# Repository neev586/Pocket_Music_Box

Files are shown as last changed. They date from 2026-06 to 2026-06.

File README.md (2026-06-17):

# Pocket Music Box

A small 3D-printed music box that plays MP3s when the lid opens and pauses when it closes — like a classic ballerina music box, but with your own songs.

## How It Works

- **Open the lid** → music plays
- **Close the lid** → music pauses instantly
- **Reopen within 20 seconds** → resumes where it left off
- **Reopen after 20 seconds** → restarts the track from the beginning
- **Short press the button** → skip to the next track
- **Long press the button (0.5s+)** → cycle through 5 volume levels (mute → low → medium → high → max)
- **Lid stays closed for 60 seconds** → ESP32 enters deep sleep to save battery
- **Deep sleep** → wakes every 1.5 seconds to check if the lid is open

## Components

| Component | Specification |
|---|---|
| Microcontroller | ESP32-C3 Super Mini |
| Audio module | MP3-TF-16P (DFPlayer Mini clone) |
| Speaker | 40mm 8Ω |
| Battery | 3.7V LiPo, 300mAh (32×20×6mm) |
| Charger | TP4056 USB-C module |
| Light sensor | Photoresistor (LDR) |
| Button | 6×6mm tactile push button |
| Resistor | 10kΩ × 1 (LDR pull-down) |
| SD card | MicroSD, FAT32, 32GB or smaller |

## Wiring

```
POWER
  Battery +        → TP4056 B+
  Battery −        → TP4056 B−
  TP4056 OUT+      → ESP32 5V pin + DFPlayer VCC
  TP4056 OUT−      → GND rail (shared by all components)

ESP32 → DFPlayer (serial)
  GPIO 7 (TX)      → DFPlayer RX
  GPIO 6 (RX)      → DFPlayer TX

DFPlayer → Speaker
  SPK_1            → Speaker +
  SPK_2            → Speaker −

Button
  GPIO 9           → one leg
  other leg        → GND
  (uses internal pull-up, no external resistor needed)

LDR (light sensor)
  3.3V → LDR → junction → 10kΩ → GND
                 ↓
              GPIO 0
```

## SD Card Setup

- Format as **FAT32** (not exFAT or NTFS)
- Maximum **32GB** card
- Place MP3 files in the **root folder** (not in subfolders)
- Name files: `001.mp3`, `002.mp3`, `003.mp3`, etc.

## Software Setup

### Arduino IDE Settings

- **Board:** Nologo ESP32C3 Super Mini (or ESP32C3 Dev Module)
- **USB CDC On Boot:** Enabled
- **Flash Frequency:** 80MHz

### Required Library

- [DFRobotDFPlayerMini](https://github.com/DFRobot/DFRobotDFPlayerMini) — install via Arduino Library Manager

### First Upload

If the board connects and disconnects repeatedly when first plugged in, hold the **BOOT button** while plugging in the USB cable, then release after 1 second. Upload your sketch in this state. Subsequent uploads will work normally.

## Enclosure

The enclosure is a 3D-printed hinged box designed to house all components.

### Dimensions

- **Exterior (closed):** 68 × 60 × 52mm (68.5mm deep including hinge)
- **Interior:** 62.4 × 54.4 × 43.2mm
- **Wall thickness:** 2.8mm
- **Lid thickness:** 6mm

### Features

- 5-knuckle barrel hinge (2mm pin)
- Speaker grille on the front wall (40mm, concentric ring pattern)
- 6.4mm square button hole on the right wall
- SD card module holder on the right wall (flat mount, card accessible from top with lid open)
- Battery cradle (back-left)
- USB-C charge port opening on the back wall (14 × 8mm)

### Printing

- **Material:** PLA
- **Layer height:** 0.2mm
- **Walls:** 3 perimeters
- **Infill:** 15%
- **Supports:** none for the body; light support may be needed under the lid's hinge knuckles
- **Hinge pin:** insert a 2mm steel rod or length of filament after printing

### Files

- `enclosure_body.stl` — print floor-down as-is
- `enclosure_lid.stl` — pre-oriented top-face-down for printing
- `enclosure.py` — parametric source (Python + trimesh), edit variables and re-run to customize

## Deep Sleep & Power

The ESP32-C3 draws ~50–80mA when active. After 60 seconds with the lid closed, it enters deep sleep (~0.1–0.2mA average with 1.5-second wake checks). The 300mAh battery lasts:

- **Active playback:** ~4–5 hours
- **Deep sleep:** ~60–90 days

## Troubleshooting

| Symptom | Likely Cause | Fix |
|---|---|---|
| ESP32 connects/disconnects on USB | Empty flash | Hold BOOT button while plugging in, then upload |
| DFPlayer not found | Loose wiring or power issue | Check and reflow solder joints on VCC, GND, TX, RX |
| No sound but DFPlayer online | SD card issue | Reformat as FAT32, rename files to 001.mp3 format |
| Audio plays but is silent | Speaker wiring | Check SPK_1 and SPK_2 connections |
| LDR always reads 4095 | Missing pull-down resistor | Add 10kΩ between GPIO 0 and GND |
| Box won't wake from sleep | LDR covered or broken | Check that light reaches the LDR when lid opens |
| Stops working after charging | Solder joint cracked from heat | Reflow all DFPlayer solder joints |
| Audio distorts at max volume | Speaker overdriven | Lower top volume step from 30 to 25 |
| Stuck on "Initialization failed" | DFPlayer boots slower than ESP32 | Press reset button; if persistent, check wiring |

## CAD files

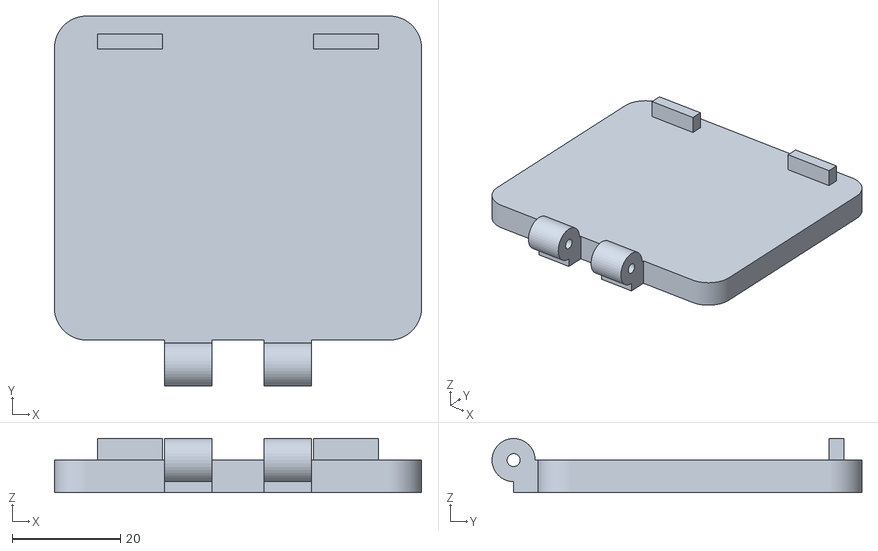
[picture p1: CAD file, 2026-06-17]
Enclosure/enclosure_lid_final.stl
68.0 x 68.5 x 10.0

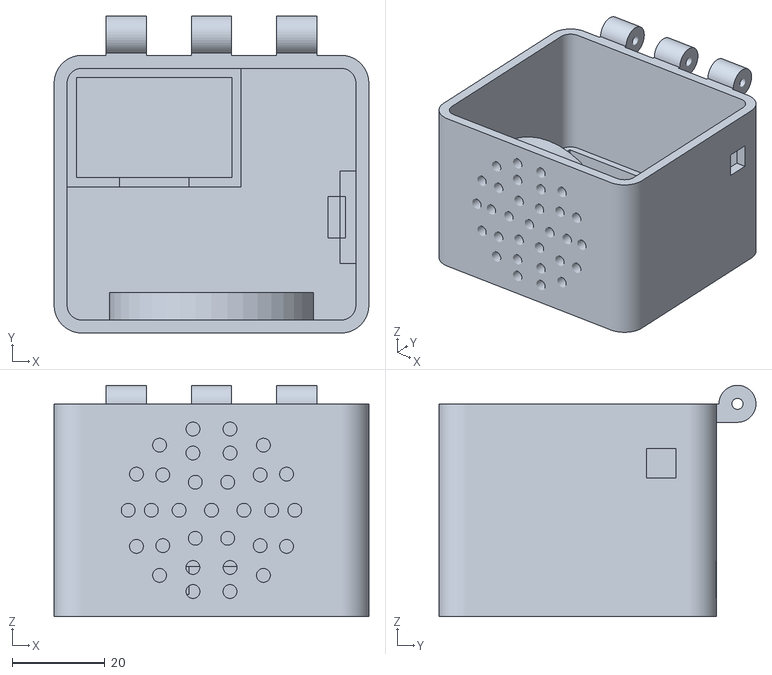
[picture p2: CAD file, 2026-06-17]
Enclosure/enclosure_body_final.stl
68.0 x 68.5 x 50.0

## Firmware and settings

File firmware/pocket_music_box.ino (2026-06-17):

#include "Arduino.h"
#include "DFRobotDFPlayerMini.h"
#include <Preferences.h>

// ==========================================
// PIN DEFINITIONS
// ==========================================
#define FPS_RX 6      // ESP32 RX (Can leave disconnected)
#define FPS_TX 7       // ESP32 TX -> Connects to 1k resistor -> DFPlayer RX
#define BUTTON_PIN 9   // Song cycle / Volume button -> Connects to GPIO 4 and GND
#define LDR_PIN 0      // Photoresistor -> Connects to GPIO 0 (Analog pin)

// ==========================================
// CALIBRATION & TIMING CONFIGURATION
// ==========================================
const int LIGHT_THRESHOLD = 1000;       // LDR threshold (0-4095)
const unsigned long TIME_LIMIT = 20000; // Resume window (20 sec)
const unsigned long LONG_PRESS_TIME = 500;       // Long press = volume cycle
const unsigned long SLEEP_TIMEOUT = 60000;       // Sleep after 60 sec lid-closed
const uint64_t SLEEP_INTERVAL_US = 1 * 1500000;  // Wake every 1.5 second

// ==========================================
// GLOBAL VARIABLES
// ==========================================
HardwareSerial mySerial(1);
DFRobotDFPlayerMini myDFPlayer;
Preferences prefs;

unsigned long buttonPressTime = 0;
bool buttonActive = false;

bool boxWasOpen = false;
unsigned long boxCloseTime = 0;

int currentTrack = 1;
int totalTracks = 0;
int volumeStep = 2;
const int volumeLevels[] = {0, 12, 18, 24, 30};

bool wokeFromSleep = false;

// ==========================================
// HELPER: Save state and enter deep sleep
// ==========================================
void enterDeepSleep() {
  Serial.println("Entering deep sleep...");
  prefs.putInt("track", currentTrack);
  prefs.putInt("vol", volumeStep);
  prefs.end();
  
  esp_sleep_enable_timer_wakeup(SLEEP_INTERVAL_US);
  esp_deep_sleep_start();
}

void setup() {
  pinMode(BUTTON_PIN, INPUT_PULLUP);
  analogReadResolution(12);
  
  Serial.begin(115200);

  // -------------------------------------------------------
  // DEEP SLEEP WAKE CHECK — run before full init
  // -------------------------------------------------------
  esp_sleep_wakeup_cause_t wakeReason = esp_sleep_get_wakeup_cause();

  if (wakeReason == ESP_SLEEP_WAKEUP_TIMER) {
    // Lid still closed? Stay asleep.
    int lightLevel = analogRead(LDR_PIN);
    if (lightLevel <= LIGHT_THRESHOLD) {
      esp_sleep_enable_timer_wakeup(SLEEP_INTERVAL_US);
      esp_deep_sleep_start();
    }

    // Lid is open — full wake
    wokeFromSleep = true;
    Serial.println(F("Woke from deep sleep — lid is open!"));
  }

  // -------------------------------------------------------
  // FULL INITIALIZATION
  // -------------------------------------------------------
  mySerial.begin(9600, SERIAL_8N1, FPS_RX, FPS_TX);
  Serial.println(F("Initializing Pocket Music Box..."));

  if (!myDFPlayer.begin(mySerial)) {
    Serial.println(F("Initialization failed. Check SD card or wiring!"));
    while(true);
  }

  Serial.println(F("DFPlayer Mini Online."));

  totalTracks = myDFPlayer.readFileCounts();
  if (totalTracks <= 0) {
    Serial.println("WARNING: No tracks found! Check SD card.");
    totalTracks = 10;
  }

  prefs.begin("musicbox", false);
  if (wokeFromSleep) {
    currentTrack = prefs.getInt("track", 1);
    volumeStep = prefs.getInt("vol", 2);
    Serial.print(F("Restored track: ")); Serial.println(currentTrack);
    Serial.print(F("Restored volume step: ")); Serial.println(volumeStep);
  }

  myDFPlayer.volume(volumeLevels[volumeStep]);

  if (wokeFromSleep) {
    boxWasOpen = true;
    Serial.println("Playing saved track after deep sleep.");
    myDFPlayer.play(currentTrack);
  } else {
    myDFPlayer.play(currentTrack);
    delay(200);
    myDFPlayer.pause();
  }
}

void loop() {
  // -----------------------------------------------------------------
  // 1. LID SENSOR LOGIC (PHOTORESISTOR)
  // -----------------------------------------------------------------
  int lightLevel = analogRead(LDR_PIN);
  bool isBoxOpen = (lightLevel > LIGHT_THRESHOLD);

  if (isBoxOpen && !boxWasOpen) {
    boxWasOpen = true;
    unsigned long timeSpentClosed = millis() - boxCloseTime;

    if (timeSpentClosed <= TIME_LIMIT) {
      Serial.println("Opened quickly! Resuming track.");
      myDFPlayer.start();
    } else {
      Serial.println("Opened after a while! Restarting track from start.");
      myDFPlayer.play(currentTrack);
    }
    delay(200);
  } 
  else if (!isBoxOpen && boxWasOpen) {
    myDFPlayer.pause();
    boxCloseTime = millis();
    boxWasOpen = false;
    Serial.println("Box closed. Audio paused.");
    delay(200);
  }

  // -----------------------------------------------------------------
  // 2. DEEP SLEEP CHECK (lid closed too long)
  // -----------------------------------------------------------------
  if (!isBoxOpen && !boxWasOpen) {
    unsigned long closedDuration = millis() - boxCloseTime;
    if (closedDuration > SLEEP_TIMEOUT) {
      enterDeepSleep();
    }
  }

  // -----------------------------------------------------------------
  // 3. BUTTON CONTROLS (only when lid is open)
  // -----------------------------------------------------------------
  if (isBoxOpen) {
    bool isPressed = (digitalRead(BUTTON_PIN) == LOW);

    if (isPressed && !buttonActive) {
      buttonActive = true;
      buttonPressTime = millis();
    } 
    else if (!isPressed && buttonActive) {
      long pressDuration = millis() - buttonPressTime;
      buttonActive = false;

      if (pressDuration < LONG_PRESS_TIME) {
        currentTrack++;
        if (currentTrack > totalTracks) {
          currentTrack = 1;
        }
        Serial.print("Short Press: Skipping to track ");
        Serial.println(currentTrack);
        myDFPlayer.play(currentTrack);
      } 
      else {
        volumeStep++;
        if (volumeStep > 4) {
          volumeStep = 0;
        }
        Serial.print("Long Press: Setting volume step to ");
        Serial.println(volumeStep);
        myDFPlayer.volume(volumeLevels[volumeStep]);
      }
      delay(200);
    }
  }

  delay(30);
}

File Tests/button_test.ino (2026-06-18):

#define BUTTON_PIN 9

void setup() {
  pinMode(BUTTON_PIN, INPUT_PULLUP);
  Serial.begin(115200);
  Serial.println("Button Test — press the button");
}

void loop() {
  if (digitalRead(BUTTON_PIN) == LOW) {
    Serial.println("PRESSED");
  } else {
    Serial.println("released");
  }
  delay(200);
}

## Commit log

2026-06-18 Blink test for ESP32
2026-06-18 LDR test code for light sensor readings
2026-06-18 DFPlayer test code for Arduino
2026-06-18 Button test
